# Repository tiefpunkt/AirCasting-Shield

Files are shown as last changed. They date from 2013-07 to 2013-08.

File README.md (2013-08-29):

# Aircasting Shield
Airquality sensing sensor shield for Arduino. To be used with Bluetooth Shield, for http://www.aircasting.org/.

## Test on PC
Connect to bluetooth chip via `sudo rfcomm connect /dev/rfcomm0 00:13:EF:12:1C:B2`.
If different chip, get ID via `hcitool scan`

## See also
More information on the build over at http://hackingroom.de/wiki/AirCasting_Shield

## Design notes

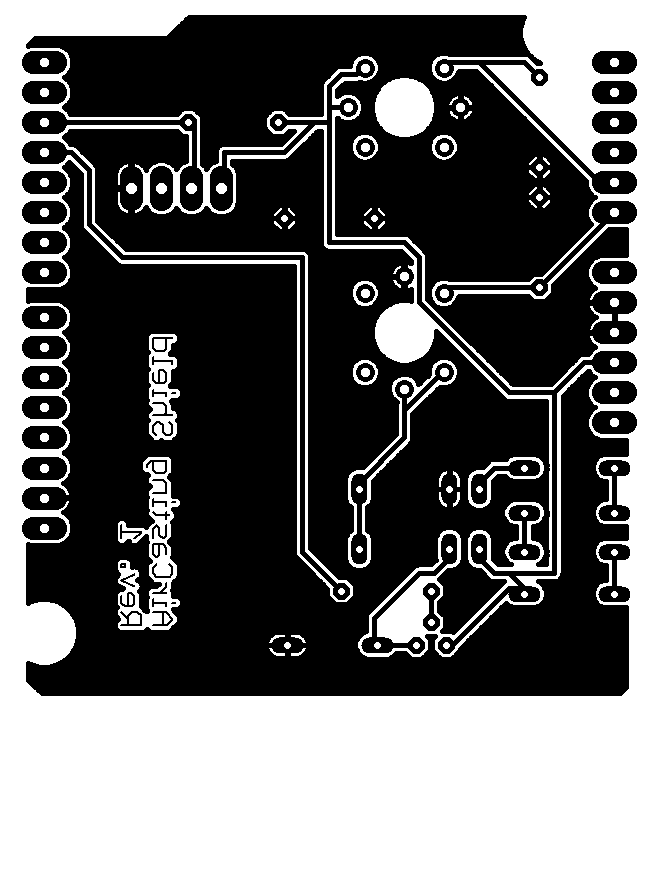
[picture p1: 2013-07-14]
shield.png

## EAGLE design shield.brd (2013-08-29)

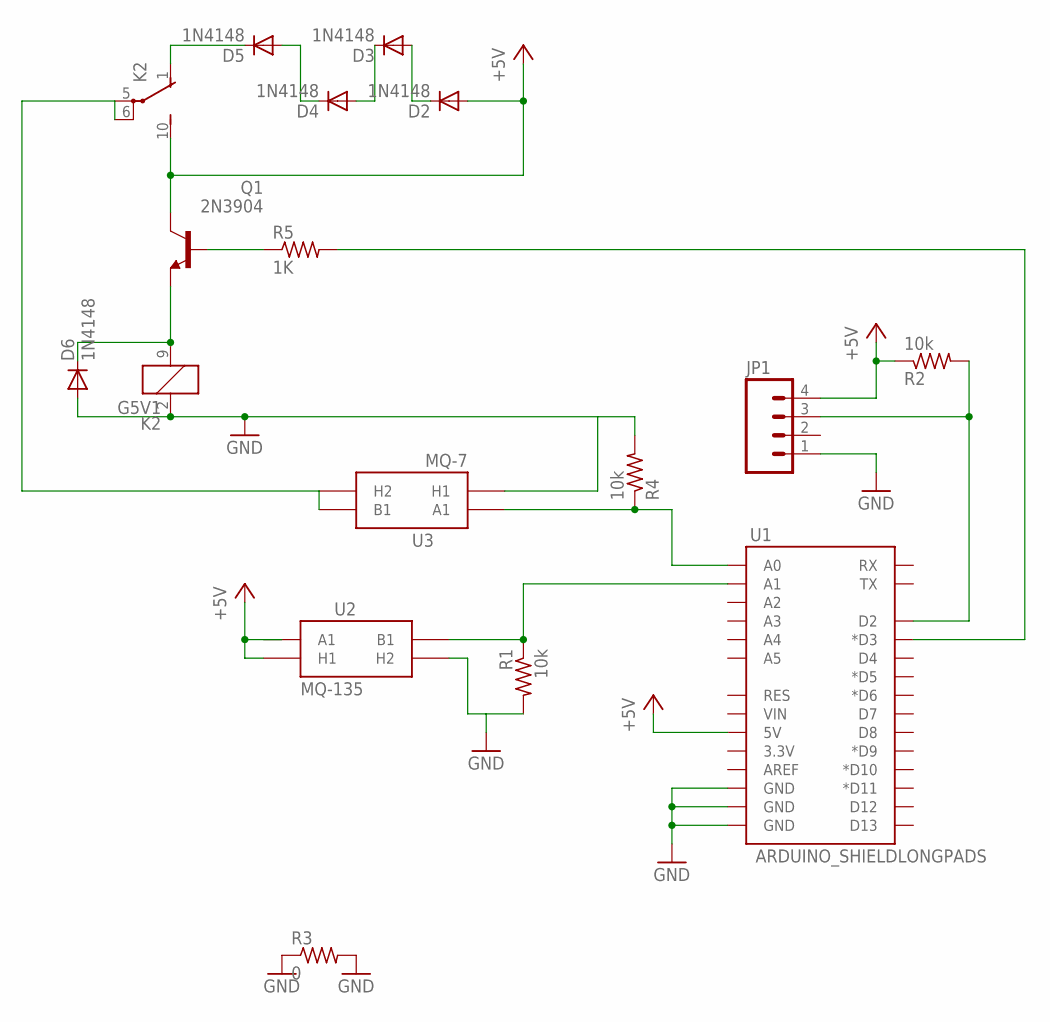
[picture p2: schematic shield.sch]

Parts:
D2, D3, D4, D5, D6: 1N4148; DO35-7
JP1: M04LONGPADS; 1X04_LONGPADS
K2: G5V1
Q1: 2N3904; TO92
R1, R2, R4: 10k; 0204/7
R3: 0; 0204/7
R5: 1K; 0204/7
U1: ARDUINO_SHIELDLONGPADS; DUEMILANOVE_SHIELD_LONGPADS
U2: MQ-135; MQ-3
U3: MQ-7; MQ-3

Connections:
+5V: D2.A, JP1.4, K2.10 (S), Q1.1 (C), R2.1, U1.5V, U2.A1, U2.HA (H1)
GND: D6.A, JP1.1, K2.2 (1), R1.2, R3.1, R3.2, R4.2, U1.GND@0 (GND), U1.GND@1 (GND), U1.GND@2 (GND), U2.HB (H2), U3.HA (H1)
unnamed: R5.2, U1.D3 (*D3)
unnamed: R1.1, U1.A1, U2.B1
unnamed: JP1.3, R2.2, U1.D2
unnamed: D2.C, D3.A
unnamed: K2.5, K2.6, U3.B1, U3.HB (H2)
unnamed: D3.C, D4.A
unnamed: D4.C, D5.A
unnamed: D5.C, K2.1 (O)
unnamed: D6.C, K2.9 (2), Q1.3 (E)
unnamed: Q1.2 (B), R5.1
SENSOROUT: R4.1, U1.A0, U3.A1

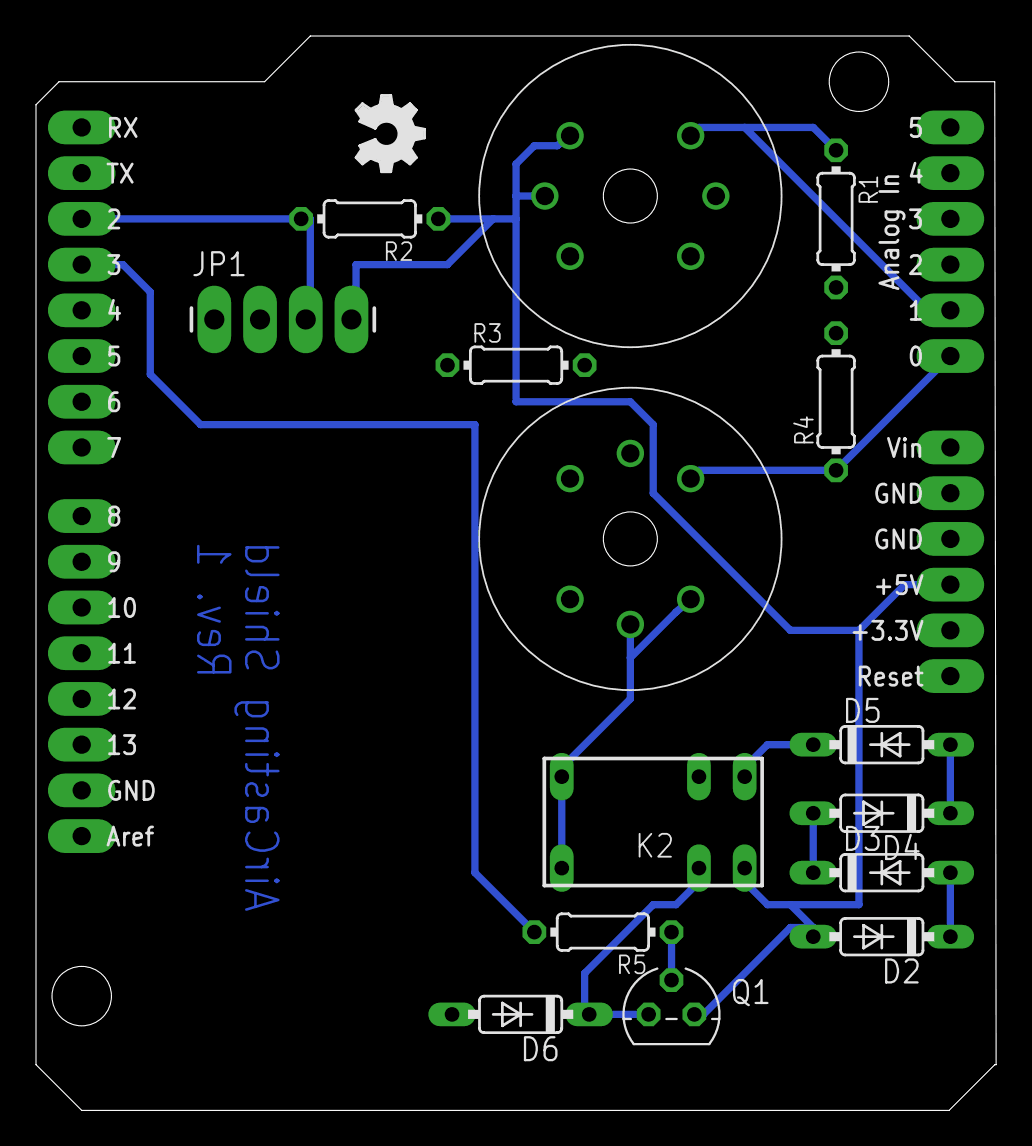
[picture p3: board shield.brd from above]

Board: 2 copper layers, 53.3 x 59.7 mm, 17 parts (0 on the bottom side), 13 nets.

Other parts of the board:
U$1: OSHW_FILLX150_NOTEXT

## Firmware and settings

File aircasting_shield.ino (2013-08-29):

#include "DHT.h"
#include "SimpleTimer.h"
#include "SoftwareSerial.h"

#define DHTPIN 2    
#define DHTTYPE DHT22 //DHT11, DHT21, DHT22

#define RELAIS 3
#define MQ_7 0
#define MQ_135 1

#include <CS_MQ7.h>

CS_MQ7 MQ7(3, 13);

DHT dht(DHTPIN, DHTTYPE);

SimpleTimer timer1;

SoftwareSerial bluetooth(6, 7); 

void setup()
{
  // Setup relais for MQ7
  pinMode(RELAIS, OUTPUT);
  digitalWrite(RELAIS, LOW);

  // Setup DHT22
  dht.begin();

  // Setup Serial connection
  Serial.begin(9600);

  // Setup Bluetooth Adapter
  bluetooth.begin(38400);
  bluetooth.print("\r\n+STWMOD=0\r\n"); //set the bluetooth work in slave mode
  bluetooth.print("\r\n+STNA=AirCastingSensor\r\n"); //set the bluetooth name as "SeeedBTSlave"
  bluetooth.print("\r\n+STOAUT=1\r\n"); // Permit Paired device to connect me
  bluetooth.print("\r\n+STAUTO=0\r\n"); // Auto-connection should be forbidden here
  delay(2000); // This delay is required.
  bluetooth.print("\r\n+INQ=1\r\n"); //make the slave bluetooth inquirable 
  delay(2000); // This delay is required.
  bluetooth.flush();


  timer1.setInterval(5000, processSensors);
}
 
void loop() {
  MQ7.CoPwrCycler();
  timer1.run();
}

void processSensors() {
  processDHT22();
  processMQ7();
  processMQ135();
  Serial.println();
}

void processDHT22() {
  float h = dht.readHumidity();     //Luftfeuchte auslesen
  float t = dht.readTemperature();  //Temperatur auslesen
 
  // Prüfen ob eine gültige Zahl zurückgegeben wird. Wenn NaN (not a number) zurückgegeben wird, dann Fehler ausgeben.
  if (isnan(t) || isnan(h)) {
    Serial.println("DHT22 konnte nicht ausgelesen werden");
  } else {
    Serial.print("Luftfeuchte: ");
    Serial.print(h);
    Serial.print(" %\t");
    Serial.print("Temperatur: ");
    Serial.print(t);
    Serial.print(" C\t");
    
    bluetooth.print(h);
    bluetooth.print(";AirCastingShieldRev1;DHT22H;Humidity;RH;percent;%;0;25;50;75;100");
    bluetooth.print("\n");
    bluetooth.print(t);
    bluetooth.print(";AirCastingShieldRev1;DHT22T;Temperature;C;degrees Celsius;C;0;10;15;20;25");
    bluetooth.print("\n");
  }
}

void processMQ7() {
  if(MQ7.CurrentState() == LOW){   //we are at 1.4v, read sensor data!
    int sensor1 = analogRead(MQ_7);
    float voltage = sensor1 * 5.0 / 1024;
    Serial.print("MQ7: ");
    Serial.print(voltage);
    Serial.print("V\t");
    
    float CO = map(sensor1, 0 , 1023, 0.0, 100.0);
    bluetooth.print(CO);
    bluetooth.print(";AirCastingShieldRev1;MQ7;CO Gas;CO;response indicator;RI;0;25;50;75;100");
    bluetooth.print("\n");
    
  } else {
    Serial.print("MQ7: HEATING\t");
  }
}

void processMQ135() {
    int sensor2 = analogRead(MQ_135);
    float voltage = sensor2 * 5.0 / 1024;
    Serial.print("MQ135: ");
    Serial.print(voltage);
    Serial.print("V");
    
    float VOC = map2(sensor2, 0 , 1023, 0.0, 100.0);
    bluetooth.print(VOC);
    bluetooth.print(";AirCastingShieldRev1;MQ135;VOC;VOC;response indicator;RI;0;25;50;75;100");
    bluetooth.print("\n");
}

float map2(float x, float in_min, float in_max, float out_min, float out_max) {
  return (x - in_min) * (out_max - out_min) / (in_max - in_min) + out_min;
}

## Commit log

2013-08-29 changes to the board
    [shield.brd, shield.sch]
2013-08-29 Arduino sources for rev 1 shield with bluetooth on Arduino Leonardo

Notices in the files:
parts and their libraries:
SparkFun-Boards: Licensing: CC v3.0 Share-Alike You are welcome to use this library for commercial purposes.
